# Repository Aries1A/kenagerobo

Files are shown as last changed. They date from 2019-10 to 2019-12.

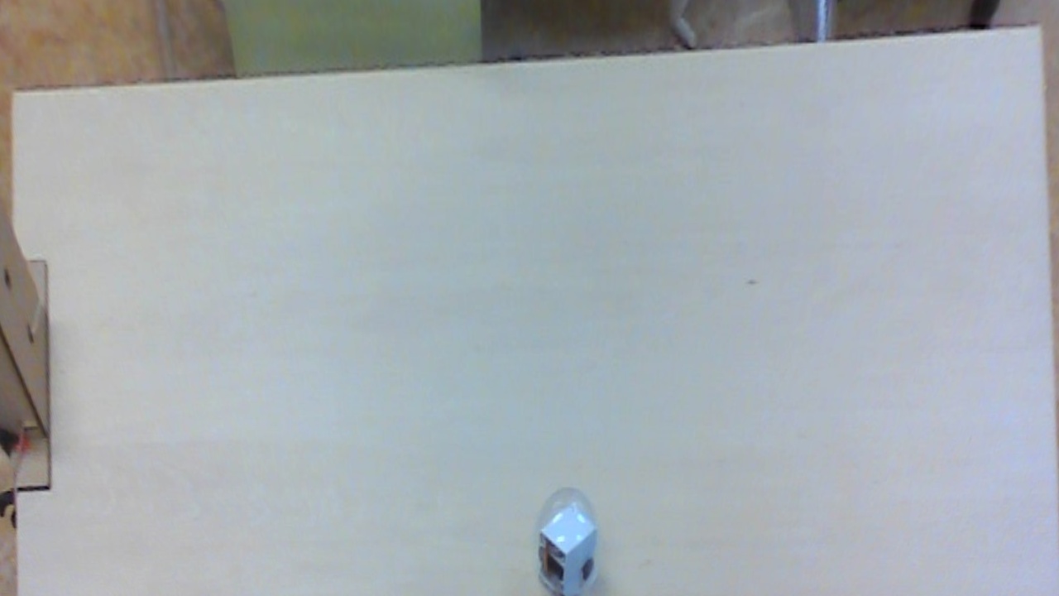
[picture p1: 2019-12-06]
src/pyscript/Q_learning/imgs/img_square/90_90.jpg

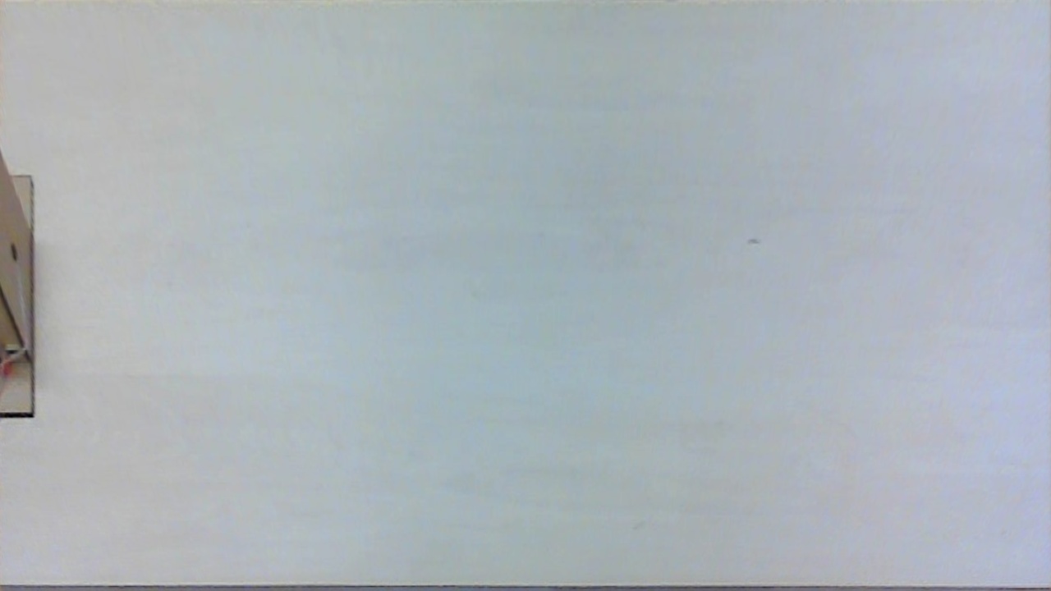
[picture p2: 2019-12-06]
src/pyscript/Q_learning/imgs/img_square/camera_capture_0.jpg

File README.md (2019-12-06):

# kenagerobo

## 概要
KenageRoboは、「[東京大学制作展 2019 ああ言えば、こう言う。こう言えば、どう言う？](http://www.iiiexhibition.com/)」にて制作・展示した作品です。

思わず応援したくなるロボットに出会ったことはありますか。

KenageRoboは強化学習をするロボットの「健気さ」をテーマとした作品です。

ロボットに与えられた課題は「制限時間内にゴールまで進むこと」。

何度失敗してもひたむきに挑戦し続ける球ロボットの成長日記です。

# デモ動画
画像をクリックで動画を再生(youtubeに飛びます)

KenageRobo (https://www.youtube.com/watch?v=YKGPmpQyom0&feature=youtu.be)

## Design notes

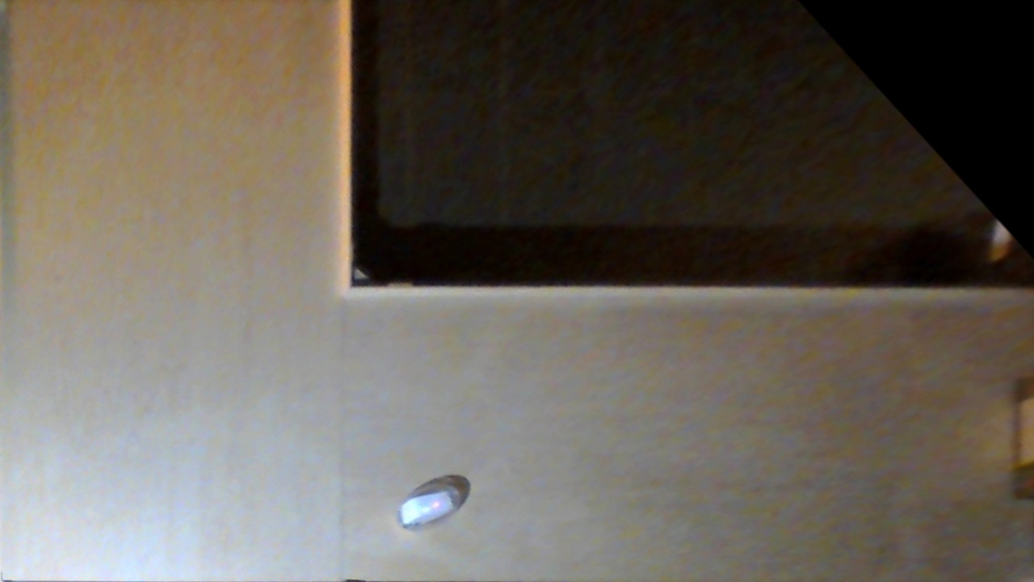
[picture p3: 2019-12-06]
src/pyscript/Q_learning/imgs/img_forum_square/camera_capture_3.jpg

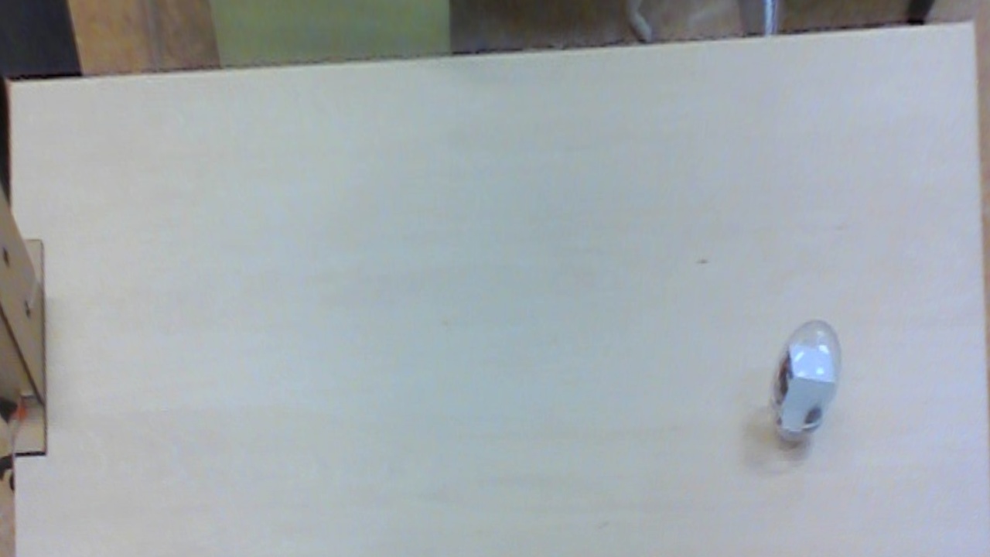
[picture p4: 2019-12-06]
src/pyscript/Q_learning/imgs/img_square/147_24_Li.jpg

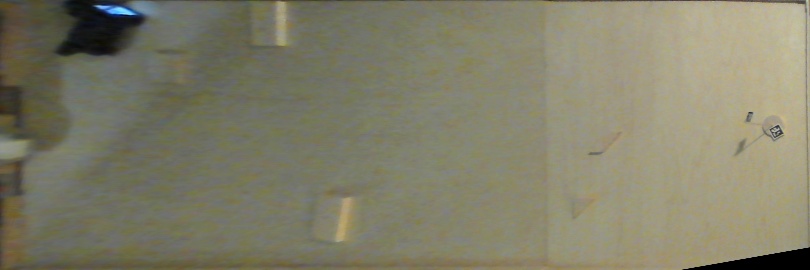
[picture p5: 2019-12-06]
src/pyscript/Q_learning/imgs/baseline/base_0.jpg

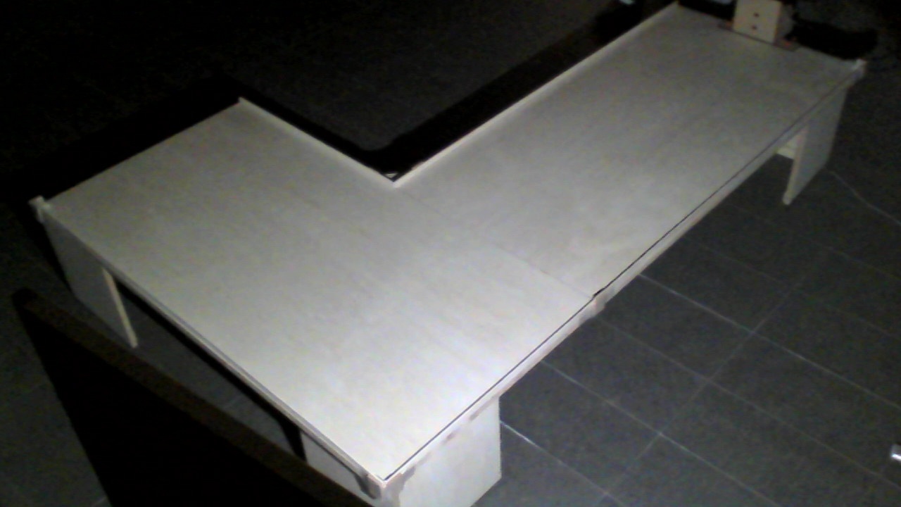
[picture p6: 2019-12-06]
src/pyscript/Q_learning/imgs/img_forum/camera_capture_0.jpg

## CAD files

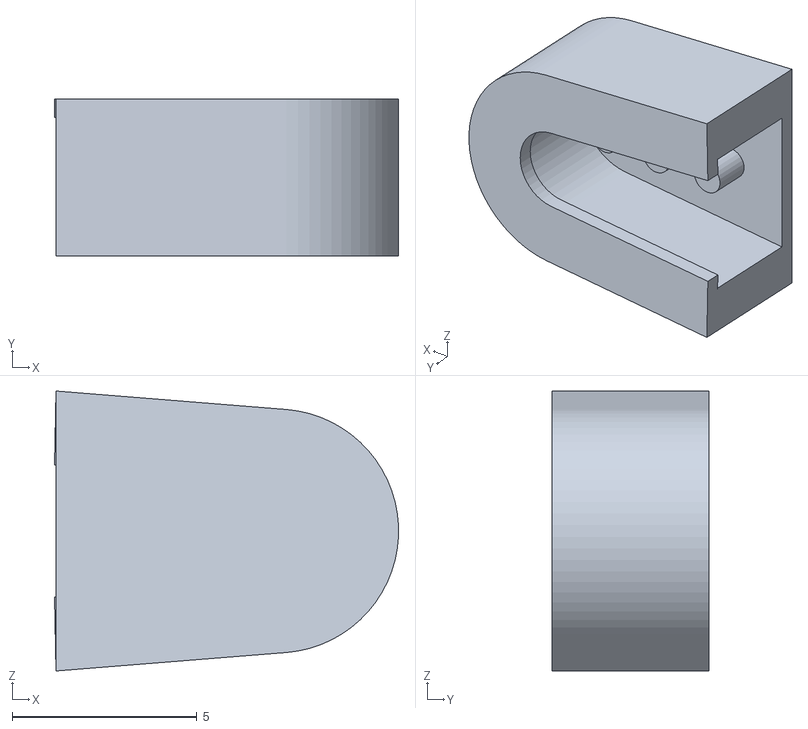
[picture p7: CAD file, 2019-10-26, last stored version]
3Ddata/sjointjoint.stl
9.31 x 4.25 x 7.58

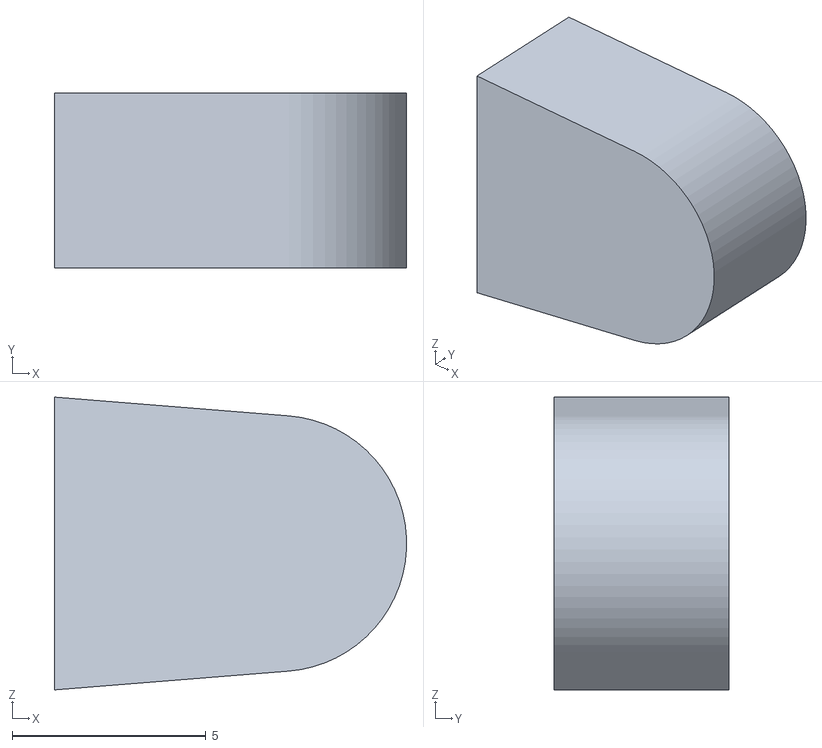
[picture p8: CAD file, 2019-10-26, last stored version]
3Ddata/sjoint v9.stl
9.07 x 4.50 x 7.55

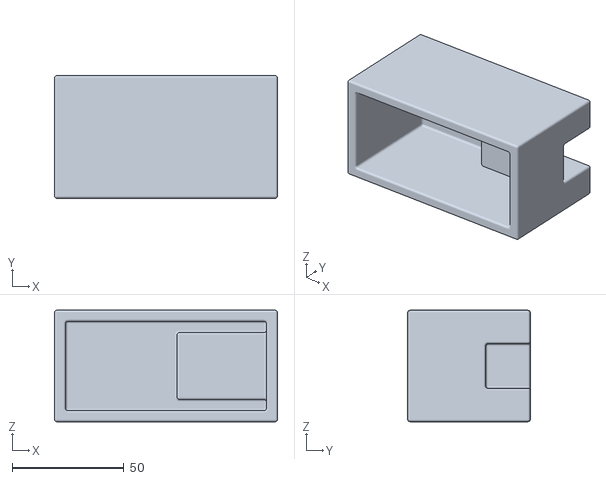
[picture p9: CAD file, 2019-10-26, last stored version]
3Ddata/kenagebox v3.stl
100.0 x 55.0 x 50.0

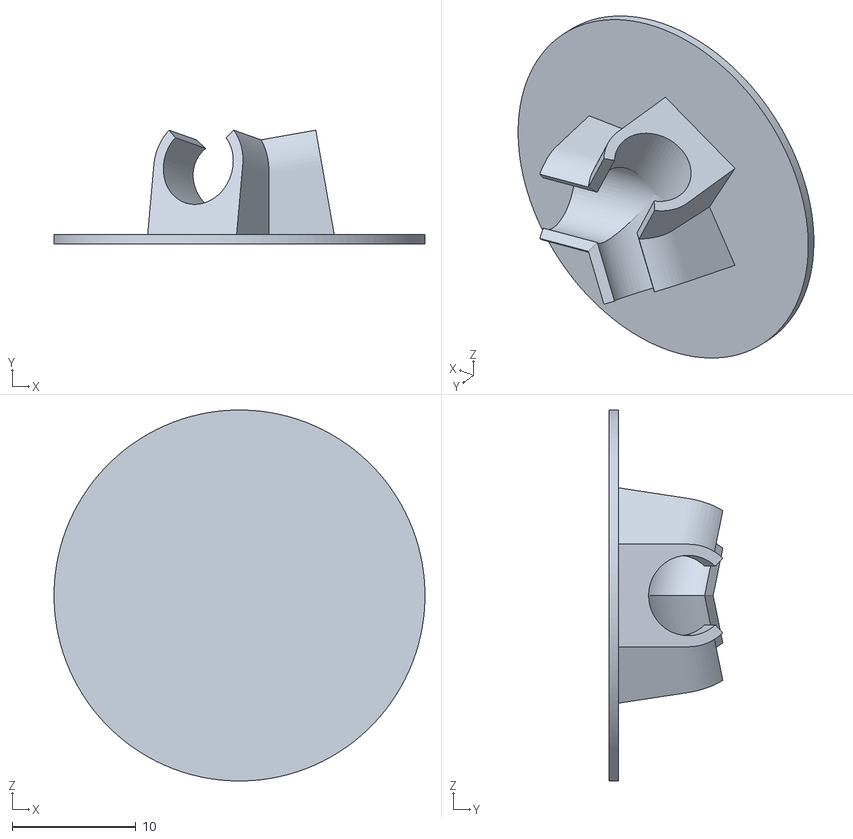
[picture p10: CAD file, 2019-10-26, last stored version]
3Ddata/3servojoint v4.stl
30.0 x 9.19 x 30.0

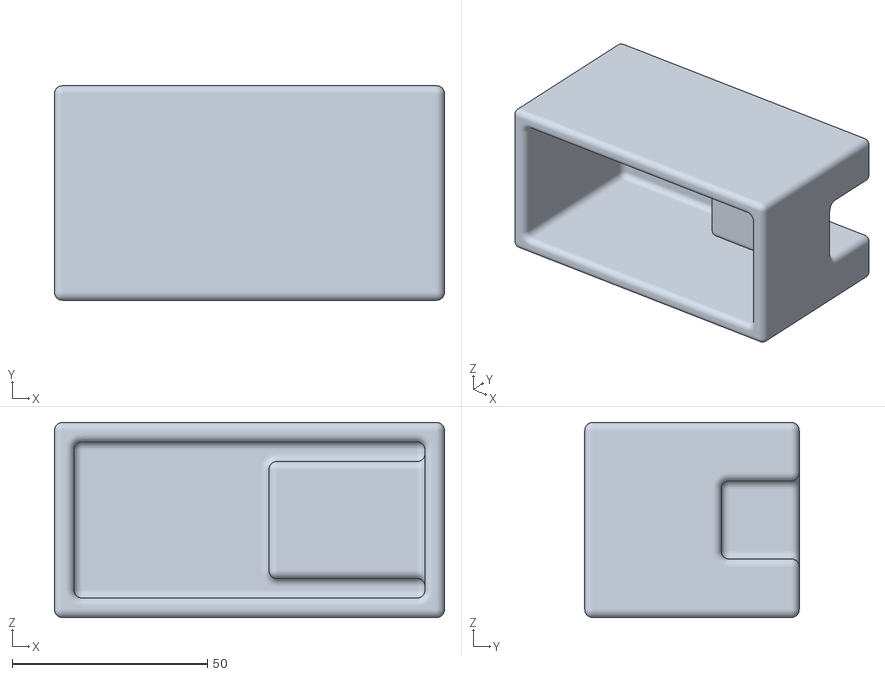
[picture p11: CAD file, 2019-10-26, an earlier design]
3Ddata/kenagebox v2.stl
100.0 x 55.0 x 50.0

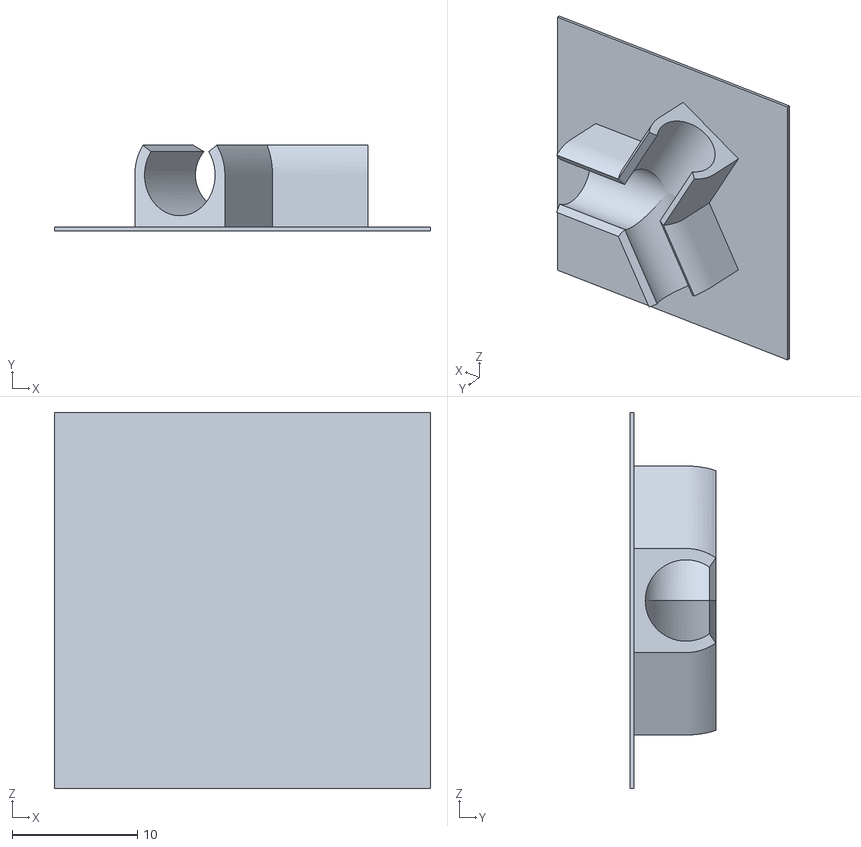
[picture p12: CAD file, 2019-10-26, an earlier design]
3Ddata/3servojoint v1.stl
30.0 x 6.83 x 30.0

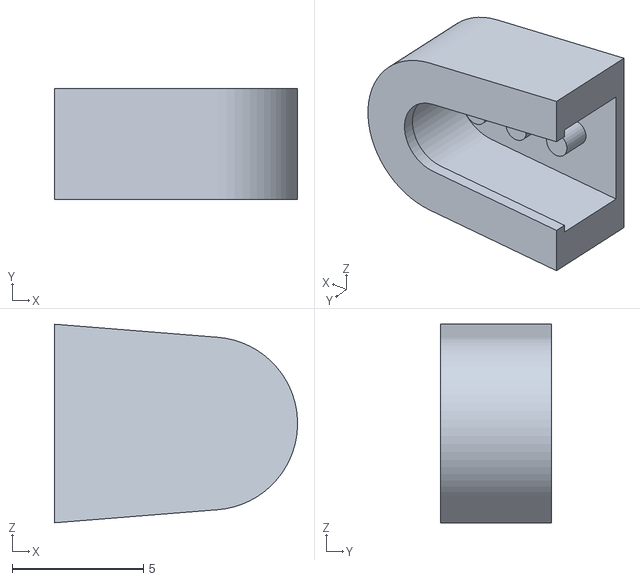
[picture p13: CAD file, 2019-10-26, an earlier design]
3Ddata/sjoint v6.stl
9.27 x 4.25 x 7.58

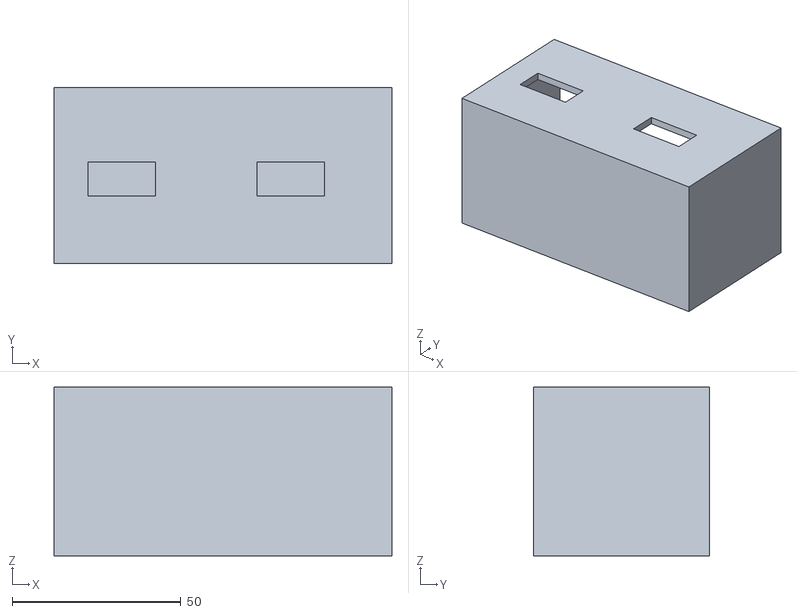
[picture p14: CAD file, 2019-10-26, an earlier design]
3Ddata/kenagebox v1.stl
100.0 x 52.0 x 50.0

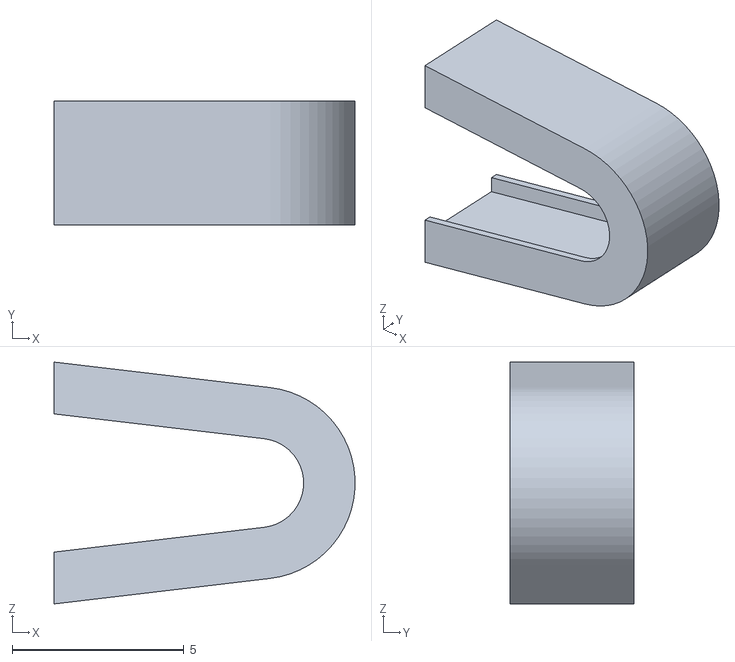
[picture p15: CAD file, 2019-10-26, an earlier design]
3Ddata/sjoint v5.stl
8.77 x 3.60 x 7.05

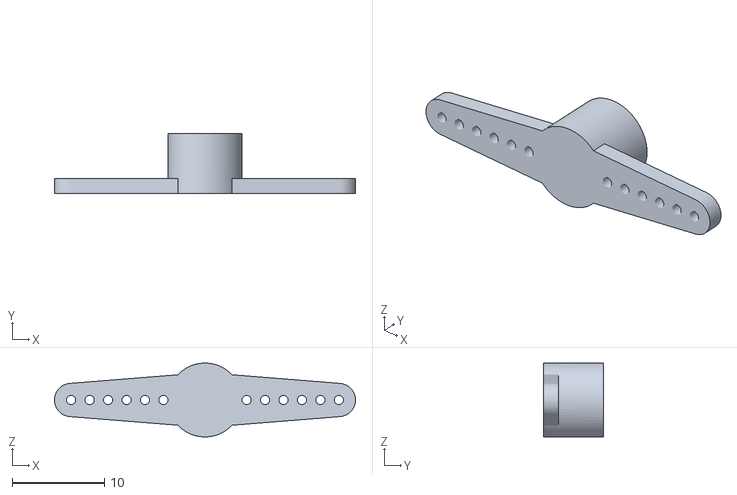
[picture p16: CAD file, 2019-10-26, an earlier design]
3Ddata/sjoint v7.stl
32.6 x 6.50 x 8.00

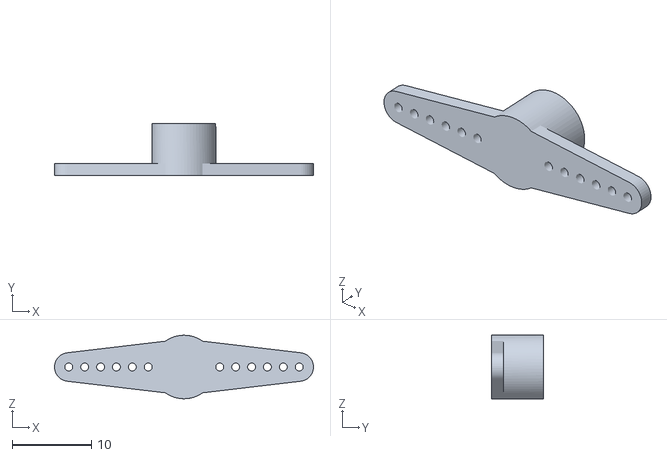
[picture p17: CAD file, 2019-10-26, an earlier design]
3Ddata/sjoint v3.stl
32.6 x 6.50 x 8.00

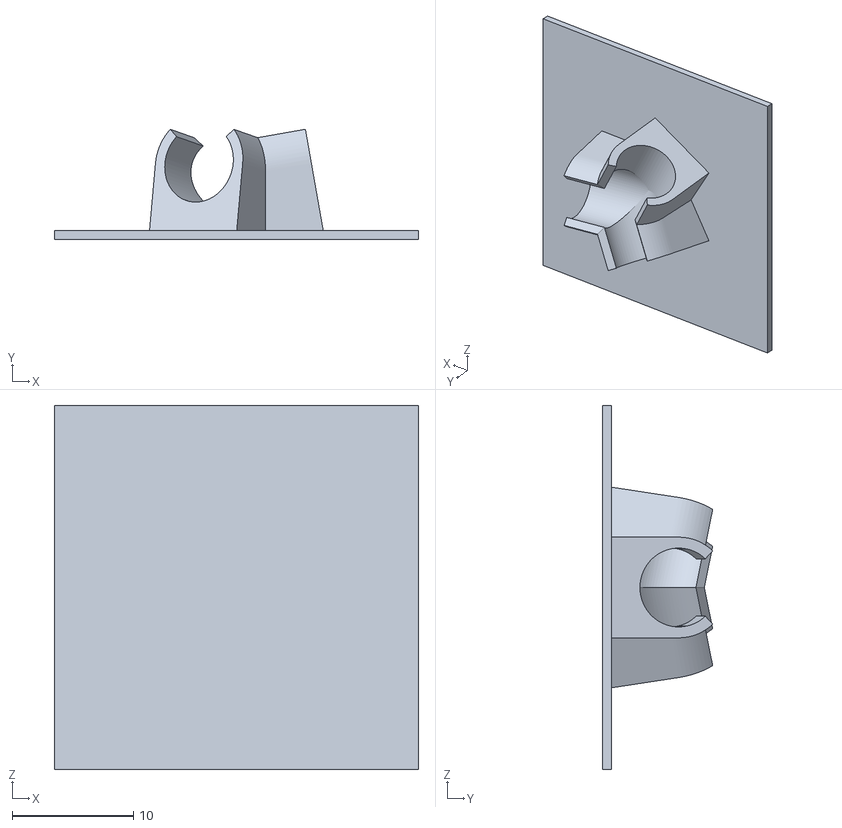
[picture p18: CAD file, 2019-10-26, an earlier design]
3Ddata/3servojoint v3.stl
30.0 x 9.10 x 30.0

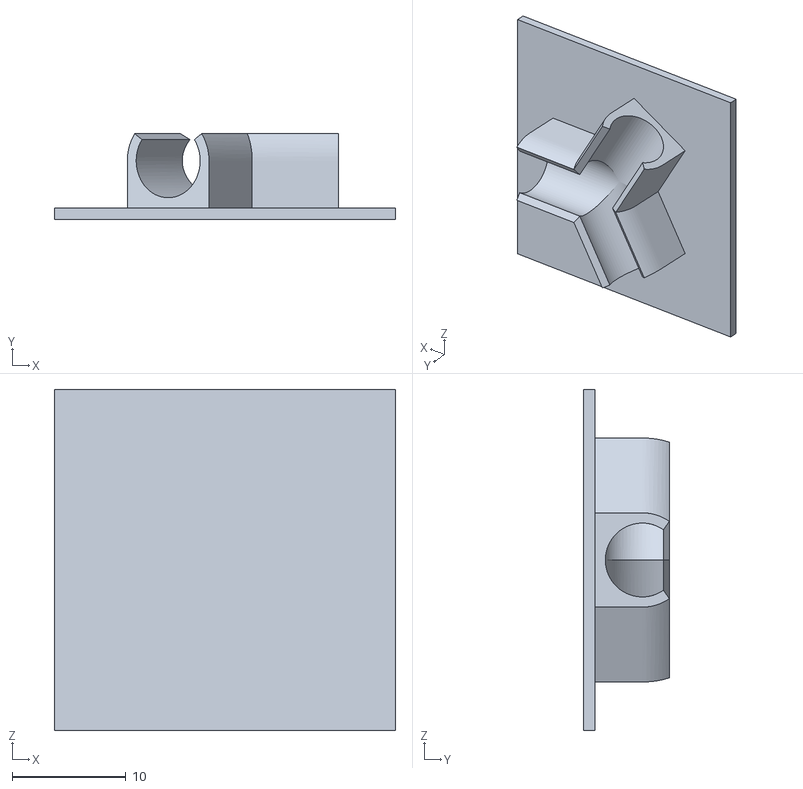
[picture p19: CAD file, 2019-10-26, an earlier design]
3Ddata/3servojoint v2.stl
30.0 x 7.53 x 30.0

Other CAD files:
3Ddata/sjoint v8.stl
3Ddata/sjoint v4.stl
3Ddata/sjoint v1.stl
3Ddata/3servojoint v1.f3d
3Ddata/3servojoint v3.f3d
3Ddata/sjointjoint.f3d

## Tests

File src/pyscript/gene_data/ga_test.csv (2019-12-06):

2019年10月29日02:47:01$[1 | 0 | 1 | 0 | 0 | 1 | 1 | 1 | 1 | 1 | 1 | 1 | 1 | 1 | 1 | 0] | [1 | 0 | 1 | 0 | 0 | 1 | 1 | 1 | 1 | 1 | 1 | 1 | 1 | 1 | 1 | 0] | [1 | 0 | 1 | 0 | 0 | 1 | 1 | 1 | 1 | 1 | 1 | 1 | 1 | 1 | 1 | 0] | [1 | 0 | 1 | 0 | 0 | 1 | 1 | 1 | 1 | 1 | 1 | 1
2019年10月29日03:14:58$[[1 | 0 | 1 | 0 | 0 | 1 | 1 | 1 | 1 | 1 | 1 | 1 | 1 | 1 | 0 | 0] | [1 | 0 | 1 | 0 | 0 | 1 | 1 | 1 | 1 | 1 | 1 | 1 | 1 | 1 | 1 | 0] | [1 | 0 | 1 | 1 | 0 | 1 | 1 | 1 | 1 | 1 | 1 | 1 | 1 | 1 | 1 | 0] | [1 | 0 | 1 | 0 | 0 | 1 | 1 | 1 | 1 | 1 | 1 | 1
2019年10月29日03:15:12$[[1 | 0 | 1 | 1 | 0 | 1 | 1 | 1 | 1 | 1 | 1 | 1 | 1 | 1 | 1 | 0] | [1 | 0 | 1 | 1 | 0 | 1 | 1 | 1 | 1 | 1 | 1 | 1 | 1 | 1 | 0 | 1] | [1 | 0 | 1 | 0 | 0 | 1 | 1 | 1 | 1 | 1 | 1 | 1 | 1 | 1 | 1 | 0] | [1 | 0 | 1 | 0 | 0 | 1 | 1 | 1 | 1 | 1 | 1 | 1
2019年10月29日03:15:30$[[1 | 0 | 1 | 1 | 0 | 1 | 1 | 1 | 1 | 1 | 1 | 1 | 1 | 1 | 0 | 1] | [1 | 0 | 1 | 1 | 0 | 1 | 1 | 1 | 1 | 1 | 1 | 1 | 1 | 1 | 0 | 1] | [1 | 0 | 1 | 1 | 0 | 1 | 1 | 1 | 1 | 1 | 1 | 1 | 0 | 1 | 1 | 0] | [1 | 0 | 1 | 0 | 0 | 1 | 1 | 1 | 1 | 1 | 1 | 1
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

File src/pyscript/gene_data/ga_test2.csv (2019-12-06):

2019年10月29日03:31:23$[[1 | 0 | 1 | 0 | 0 | 1 | 0 | 0 | 0 | 1 | 1 | 0 | 0 | 0 | 1 | 0] | [0 | 0 | 0 | 0 | 1 | 0 | 0 | 0 | 0 | 1 | 1 | 0 | 1 | 0 | 1 | 1] | [1 | 1 | 1 | 0 | 0 | 0 | 0 | 1 | 0 | 0 | 0 | 0 | 1 | 0 | 0 | 0] | [1 | 0 | 0 | 1 | 0 | 0 | 0 | 0 | 1 | 1 | 1 | 1
2019年10月29日03:41:10$[[1 | 0 | 1 | 0 | 0 | 1 | 0 | 0 | 0 | 1 | 1 | 0 | 0 | 0 | 1 | 0] | [0 | 0 | 0 | 0 | 1 | 0 | 0 | 0 | 0 | 1 | 1 | 0 | 1 | 0 | 1 | 1] | [1 | 1 | 1 | 0 | 0 | 0 | 0 | 1 | 0 | 0 | 0 | 0 | 1 | 0 | 0 | 0] | [1 | 0 | 0 | 1 | 0 | 0 | 0 | 0 | 1 | 1 | 1 | 1
2019年10月29日03:43:02$[[1 | 0 | 1 | 0 | 0 | 1 | 0 | 0 | 0 | 1 | 1 | 0 | 0 | 0 | 1 | 0] | [0 | 0 | 0 | 0 | 1 | 0 | 0 | 0 | 0 | 1 | 1 | 0 | 1 | 0 | 1 | 1] | [1 | 1 | 1 | 0 | 0 | 0 | 0 | 1 | 0 | 0 | 0 | 0 | 1 | 0 | 0 | 0] | [1 | 0 | 0 | 1 | 0 | 0 | 0 | 0 | 1 | 1 | 1 | 1
2019年10月29日03:44:21$[[1 | 0 | 1 | 0 | 0 | 1 | 0 | 0 | 0 | 1 | 1 | 0 | 0 | 0 | 1 | 0] | [0 | 0 | 0 | 0 | 1 | 0 | 0 | 0 | 0 | 1 | 1 | 0 | 1 | 0 | 1 | 1] | [1 | 1 | 1 | 0 | 0 | 0 | 0 | 1 | 0 | 0 | 0 | 0 | 1 | 0 | 0 | 0] | [1 | 0 | 0 | 1 | 0 | 0 | 0 | 0 | 1 | 1 | 1 | 1
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

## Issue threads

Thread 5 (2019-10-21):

バッテリー問題

Aries1A, 2019-10-21:
- [ ] 一つの電池でサーボモータへの給電と5v降圧のespr給電をする
- [ ] 11:00-19:00の8時間持たせる

Aries1A, 2019-10-21:
- 9vの電池は450mAhで、徐々に電圧が下がっていく
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

Aries1A, 2019-10-21:
https://item.rakuten.co.jp/vshopu/218z-2101/?s-id=pc_shop_recommend&rtg=91d15c4f119e60a95795ea2765621eaf
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

Aries1A, 2019-10-21:
https://www.amazon.co.jp/%E3%83%A2%E3%83%90%E3%82%A4%E3%83%AB%E3%83%90%E3%83%83%E3%83%86%E3%83%AA%E3%83%BC-%E8%B6%85%E8%96%84%E5%9E%8B%E3%80%90%E6%9C%80%E5%B0%8F%E6%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

Aries1A, 2019-10-28:
上の1Aモバイルバッテリー2個購入で解決
コードを挿すと横幅がボールに入らなくなったので秋月のUBS-A裸コネクタに導線を半田付けした。

Closed 2019-10-28.

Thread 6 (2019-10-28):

遺伝的アルゴリズムのコードを書く

Aries1A, 2019-10-28:

Aries1A, 2019-10-28:
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

Aries1A, 2019-10-28:
GAとserver側は書けた

Aries1A, 2019-10-29:
# 学習効率と効果を高めるために
- 一回の試行の長さ = individualのビット長　
  - どれを動かすか3bit ＊ 1動作のビット長5 ＊ 動作数4 = 60
  - 1動作は 前進/後退1bit + 秒数2bit(0-3s) + 進む速度2bit(0,30,60,90)
- 一つのpopulationの中のindividualの数は10
- 1世代にかかる時間　
  - (1動作平均2s + レイテンシ1s)＊ 動作数4 ＊ individual数10

Aries1A, 2019-11-05:
自分の状態がわからないのでQ学習に乗り換える

Closed 2019-11-05.

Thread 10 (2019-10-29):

ロボットの外装を作る

Aries1A, 2019-10-29:

Aries1A, 2019-10-29:
一部分を除いてプラスチックスプレーで色をつける

Aries1A, 2019-10-29:
fusionでレンダリングしてみる

Aries1A, 2019-11-03:
# 2019/11/03出力
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

Aries1A, 2019-11-05:
新しいのに買い換えてプラスチックスプレーで塗装したい

Aries1A, 2019-11-08:
2019/11/08
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

Aries1A, 2019-11-08:
# 2019/11/08メモ
- もう少し小さめの車輪にする
- ネジが長すぎる、太すぎる
- サーボを固定する

Aries1A, 2019-11-08:
#2019/11/09修正
![Uploading case v15.png…]()

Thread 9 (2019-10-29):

遺伝子をデコードしてサーボの動作を取得する

Aries1A, 2019-10-29:
|a  |b  |c  |d |
|---|---|---|---|
|000  |2  |3  ||
|001  |5  |6  ||
|010  |2  |3  ||
|011  |5  |6  ||
|100  |2  |3  ||
|101  |5  |6  ||
|110  |2  |3  ||
|111  |5  |6  ||

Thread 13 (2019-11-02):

Q学習が使えるかテストする

Aries1A, 2019-11-02:
現在の状態

Aries1A, 2019-11-03:
Q学習を使った蛇型ロボットの目標物接近学習
https://www.jstage.jst.go.jp/article/jsoft/29/2/29_551/_pdf/-char/ja

Aries1A, 2019-11-03:
# 状態
- 球の位置 1-81 81個
- 球の向き 345°-15°,15°-45°,... 12個
- 状態数合計 81*12=972個
# 行動
- どれとどれを動かすか3通り * 前進/後退2通り * 秒数4秒1通り * 進む速度(30,90) 2通り

Aries1A, 2019-11-11:
# 状態改
- 球の位置 6**2 = 36通り
- 球の向き 6通り
- 状態数合計 36*6 = 216通り

# 行動改
- (右前,左前)(右前,後ろ)(左前,後ろ)
- 前進・後退
- 5秒
- 速度30,90

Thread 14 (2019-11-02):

esp32でWifiを変えると接続できない問題

Aries1A, 2019-11-02:
ssidとpassを変えてもWifi.localIP()が前のままでclient.connection()=0になって接続できない

Aries1A, 2019-11-02:
# 当面の解決策
WiFi.config(IPAddress(192, 168, 2, 107), WiFi.gatewayIP(), WiFi.subnetMask());
or
WiFi.config(IPAddress(157, 82, 207, 143), WiFi.gatewayIP(), WiFi.subnetMask());
を追加して固定IPアドレスを指定する

Closed 2019-11-03.

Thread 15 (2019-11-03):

キャプションを考える

Aries1A, 2019-11-03:
## メインコンセプト
- 学習中のロボットの健気さを見て欲しい

Aries1A, 2019-11-03:
## 懸案事項
- ロボットの動きが健気なのか、形が健気なのかが混ざっている
  - 後者の場合は学習後も健気に感じてしまうのではないか
    - SASUKEロボットは学習後は健気さは薄れている

Aries1A, 2019-11-08:
思わず応援したくなるロボットに出会ったことはありますか。
KenageRoboは強化学習をするロボットの「健気さ」をテーマとした作品です。
ロボットに与えられた課題は「制限時間内にゴールまで進むこと」。
何度失敗してもひたむきに挑戦し続ける球ロボットの成長日記です。

Aries1A, 2019-11-11:
"Kenage" means "admirable" ,"little" and "pretty".(上手い訳。。。🤔)
KenageRobo is a reinforcement learning robot which let you feel "Kenage".
His mission is to reach the goal within the time limit.
Have you ever seen a robot for which you can't help cheering?

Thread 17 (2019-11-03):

ロボットを初期位置に戻す機構を作る

Aries1A, 2019-11-03:
# 概要
- ロボットに透明な糸をつけて、一定時間経過すると台の端から糸が巻き取られて初期位置に戻される
- 巻き取る機構は、DCモータをつけたアルミパイプの真ん中に糸をつけてモータを回転させると糸が巻き取られる。巻き取ったあとは逆方向に回転させると糸がたるむ

Aries1A, 2019-11-03:
DCモータの制御方法
https://www.youtube.com/watch?time_continue=214&v=K9PGpOCh1Sg

Aries1A, 2019-11-08:
アクリル棒10.1cm
テグス12.5cm

Aries1A, 2019-11-11:
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

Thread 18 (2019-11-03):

完成までのシナリオ

Aries1A, 2019-11-03:
## やること
1. Q学習のアルゴリズムを書く(1.2.)
  1. Webカメラで距離とできたら向きをとる
  1. 9軸センサで向きをとる
1. 一定ステップ経つと初期位置に戻す信号を送る
1. ロボットを初期位置に戻す機構を作る
1. 糸を引っ張って初期位置に戻す機構を作る
1. 球の中で転がるようにサーボの足を変える
1. フィールドを作る
  - 柵
  - クッション
  - パイプを留める金具

Aries1A, 2019-11-11:
型の付かない糸買う🧵
たるませの処理を追加
ロボットが動くと同時にたるませる
webカメラ置く位置と方法考える
位置計測を実装
磁気センサの狂いを直す
アクションを減らす
巻き取り装置のWiFiタイムアウトをどうにかする(PCに繋いでシリアル通信してもいいかも

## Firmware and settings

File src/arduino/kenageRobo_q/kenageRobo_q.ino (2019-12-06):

#include <WiFi.h>
#include <ESPmDNS.h>
#include <WiFiUdp.h>
#include <ArduinoOTA.h>
#include <ESP32Servo.h>
#include <Math.h>
#include "Wire.h"

int16_t mx, my, mz;

Servo myservo1, myservo2, myservo3; // 右前, 後ろ, 左前

const char* ssid = "ssid"; //サーバーのSSID
const char* password = "password"; //サーバーのパスワード

const char* host = "host";

//const int IND_NUM = 10;
//const int EXECUTE_NUM = 3;
const int STEP_MAX = 40;
int state, angle;
int action;
int steps = 0;
int episode = 0;
int Qsteps;
String action_steps[2] = {"\0"};

String postToServer(String Name = "", String Data = " ");

void setup() {
  Wire.begin(); //これ重要！！
  Serial.begin(115200);
  setupMPU9255();
  Serial.println("Booting");
  WiFi.mode(WIFI_STA);
  WiFi.begin(ssid, password);
  while (WiFi.waitForConnectResult() != WL_CONNECTED) {
    Serial.println("Connection Failed! Rebooting...");
    delay(100);
    ESP.restart();
  }

  Serial.println(WiFi.localIP());

  state = 0;
  myservo1.attach(2);
  myservo2.attach(4);
  myservo3.attach(18);
  //  postToServer("_reset", String(steps));
  postToServer("set_espStep", String(steps));
  postToServer("set_angle", String(angle));
}

//実行
void execute(int state) {
  action_steps[0] = "\0";
  action_steps[1] = "\0";

  if (state == 0) {
    delay(1000);
  }
  else if (state == 1) {
    //動作
    moveServo(action);
    //測位待機
    angle = readCompass();
  }
  else if (state == 2) {

  }
  else if (state == 3) {
    //遺伝子の更新待機
    delay(100);
  }
  else if (state == 4) {
    //学習終了状態

  }
  setNextState(state);
}

//状態更新
void setNextState(int currentstate) {
  if (currentstate == 0) {
    int episodeStart = postToServer("get_episodeStart").toInt();
    if (episodeStart == 0) {
      Serial.println("not ready");
      angle = readCompass();
      state = 0;
    }
    //取得
    else {
      String action_steps_tmp = postToServer("get_action_step");
      split(action_steps_tmp, ',', action_steps);
      action = action_steps[0].toInt();
      steps = action_steps[1].toInt();
      if (action == -1) {
        ESP.restart();
      }
      Serial.println("action start");
      state = 1;
    }
  }
  else if (currentstate == 1) {
    //動作終了
    steps++;
    postToServer("set_espStep", String(steps));
    postToServer("set_angle", String(angle));
    delay(1000);
    Serial.print("Current steps: ");
    Serial.println(String(steps));
    state = 2;
  }
  else if (currentstate == 2) {
    String action_steps_tmp = postToServer("get_action_step");
    split(action_steps_tmp, ',', action_steps);
    action = action_steps[0].toInt();
    Qsteps = action_steps[1].toInt();
    if (action == -1) {
      ESP.restart();
    }
    if (steps != Qsteps) {
      if (steps % STEP_MAX == Qsteps || steps > STEP_MAX) {
        Serial.println("next episode");
        steps = 0;
        state = 0;
        episode++;
      }
      else {
        Serial.println("no action yet");
        state = 2;
      }
    }
    else {
      Serial.println("next step");
      state = 1;
    }

  }
  else if (currentstate == 3) {
    //遺伝子の更新完了
    if (postToServer("get_evalready").toInt() == 0) {
      state = 0;
    }
    //未完了
    else {
      delay(1000);
      state = 3;
    }
    //学習完了
    if (postToServer("get_isStop").toInt() == 1) {
      state = 4;
    }

  }
  else if (currentstate == 4) {
    //学習終了状態
    state = 0;
  }
}



void loop() {
  //  ArduinoOTA.handle();
  Serial.println("Current State is " + String(state));
  execute(state);
}

//ここから便利ツール的関数
//split関数
int split(String data, char delimiter, String * dst) {
  int index = 0;
  int arraySize = (sizeof(data) / sizeof((data)[0]));
  int datalength = data.length();
  //今回だけ
  dst[0] = "";
  dst[1] = "";
  for (int i = 0; i < datalength; i++) {
    char tmp = data.charAt(i);
    if ( tmp == delimiter ) {
      index++;
      if ( index > (arraySize - 1)) return -1;
    }
    else dst[index] += tmp;
  }
  return (index + 1);
}

//POST
String postToServer(String Name, String Data) {
  Serial.print("connecting to ");
  Serial.println(host);

  // Use WiFiClient class to create TCP connections
  WiFiClient client;
  const int httpPort = 80;
  if (!client.connect(host, httpPort)) {
    Serial.println("connection failed");
    return "connection failed";
  }

  // We now create a URI for the request
  // This will send the request to the server
  const String bodyJ = "{\"Name\":\"" + Name + "\",\"Data\":\"" + Data + "\"}";
  const String str = String("POST") + " http://" + host + " HTTP/1.1\r\n" +
                     "Host: " + "80" + "\r\n" +
                     "Content-Length: " + String(bodyJ.length()) + "\r\n" +
                     "Content-Type: application/json\r\n" +
                     "Connection: close\r\n\r\n";
  const String request = str + bodyJ;
  client.print(request);
  //  Serial.println(request);
  unsigned long timeout = millis();
  while (client.available() == 0) {
    if (millis() - timeout > 5000) {
      Serial.println(">>> Client Timeout !");
      client.stop();
      return "Client Timeout";
    }
  }

  // Read all the lines of the reply from server and print them to Serial
  String response = "";
  while (client.available()) {
    response = client.readStringUntil('\r');
    //    Serial.print(line);
  }

  Serial.println(response);
  Serial.println("closing connection");
  return response;
}

//void moveServo(int action) {
//  myservo1.write(90 + 80);
//  myservo3.write(90 - 80);
//  //  myservo3.write(90 + random(-60,61));
//  delay(2000);
//  myservo1.write(90);
//  myservo3.write(90);
//  delay(2000);
//}


void moveServo(int action) {
  if (action == 0) {
    myservo1.write(90 + 90);
    myservo3.write(90 - 90);
    delay(3 * 1000);
  }
  else if (action == 1) {
    myservo1.write(90 + 50);
    myservo2.write(90 - 50);
    delay(1 * 1000);
  }
  else if (action == 2) {
    myservo3.write(90 - 50);
    myservo2.write(90 + 50);
    delay(1 * 1000);
  } else if (action == 3) {
    myservo1.write(90 - 90);
    myservo3.write(90 + 90);
    delay(1 * 1000);
    myservo1.write(90);
    myservo2.write(90);
    myservo3.write(90);
    myservo1.write(90 + 50);
    myservo2.write(90 - 50);
    delay(1 * 1000);
  } else if (action == 4) {
    myservo1.write(90 - 90);
    myservo3.write(90 + 90);
    delay(1 * 1000);
    myservo1.write(90);
    myservo2.write(90);
    myservo3.write(90);
    myservo3.write(90 - 50);
    myservo2.write(90 + 50);
    delay(1 * 1000);
  }
  myservo1.write(90);
  myservo2.write(90);
  myservo3.write(90);
}

int readCompass() {
  Wire.beginTransmission(0x0C);
  Wire.write(0x02);
  Wire.endTransmission();
  Wire.requestFrom(0x0C, 1);

  uint8_t ST1 = Wire.read();
  if (ST1 & 0x01) {
    Wire.beginTransmission(0x0C);
    Wire.write(0x03);
    Wire.endTransmission();
    Wire.requestFrom(0x0C, 7);
    uint8_t i = 0;
    uint8_t buf[7];
    while (Wire.available()) {
      buf[i++] = Wire.read();
    }
    if (!(buf[6] & 0x08)) {
      mx = ((int16_t)buf[1] << 8) | buf[0];
      my = ((int16_t)buf[3] << 8) | buf[2];
      mz = ((int16_t)buf[5] << 8) | buf[4];
    }
  }
  mx -= -82;
  my -= 94;
  mz -= 8;
  mx -= 16;
  my -= -18;
  mz -= -6;
  int angle = atan2(mx, my) / M_PI / 2 * 360 + 180 + 90;
  //    String Data = String(mx) + "," + String(my) + "," + String(mz);
  if (angle > 360) {
    angle -= 360;
  }
  Serial.println(angle);
  return angle;
}

void setupMPU9255() {
  Wire.beginTransmission(0x68);
  Wire.write(0x6B);
  Wire.write(0x00);
  Wire.endTransmission();

  Wire.beginTransmission(0x68);
  Wire.write(0x1A);
  Wire.write(0x05);
  Wire.endTransmission();

  Wire.beginTransmission(0x68);
  Wire.write(0x37);
  Wire.write(0x02);
  Wire.endTransmission();

  Wire.beginTransmission(0x0C);
  Wire.write(0x0A);
  Wire.write(0x16);
  Wire.endTransmission();
  delay(500);
}

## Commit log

2019-10-26 add esp32 code
    [3servojoint v1.f3d, 3servojoint v1.stl, 3servojoint v2.stl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]
2019-10-26 add esp32test
2019-11-08 [Enhance] add Q-learning code
    [11_5.csv, 11_5_calib.csv, MPUcalib.csv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]
2019-11-16 [Enhance] complete v2
    [q_data.csv]
2019-11-17 [Enhance] complete v2
    Former-commit-id: 8608dd888dfe8593d33baf82297842b1372dc8d4
    [11_5.csv, Drawing1.dxf, action.xlsx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]
2019-12-06 [fix] arrange folder
    Former-commit-id: a1293ffe4717ce2c7df9a400d503dd0acd4c00c3
    Former-commit-id: 4703fc292e8d33fa9ce27e66c9646ea67b444e7e
    [MPUcalib.csv, MPUcalib.xlsx, action.xlsx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]
2019-12-06 [fix] arrange folder
    Former-commit-id: 8e155cbdbdc58237029e7f15a7fc95c075bc8c8a
    [11_5.csv, 11_5_calib.csv, 3servojoint v1.f3d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]
